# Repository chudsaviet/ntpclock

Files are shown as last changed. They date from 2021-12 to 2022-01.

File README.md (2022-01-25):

NTP synchronized desktop 7-segment clock
=======================================================
Features
--------
1. **NTP** sunchronization using WiFi.
2. **RTC** backup - will show time from a high precision RTC if WiFi is not available.
3. Automatic display **brightness** control.
4. Automatic **timezone** data update from online TZDATA database.
5. Settings via WiFi AP mode and a web page.

Pictures
--------
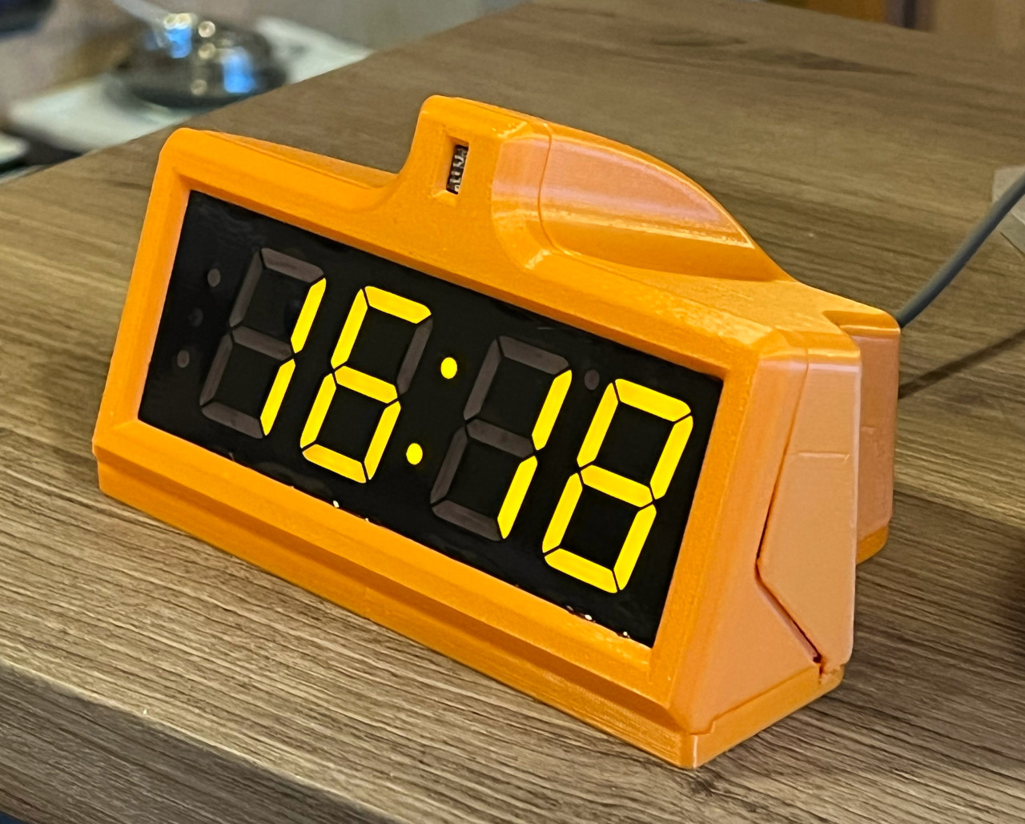
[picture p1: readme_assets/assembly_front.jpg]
Front view

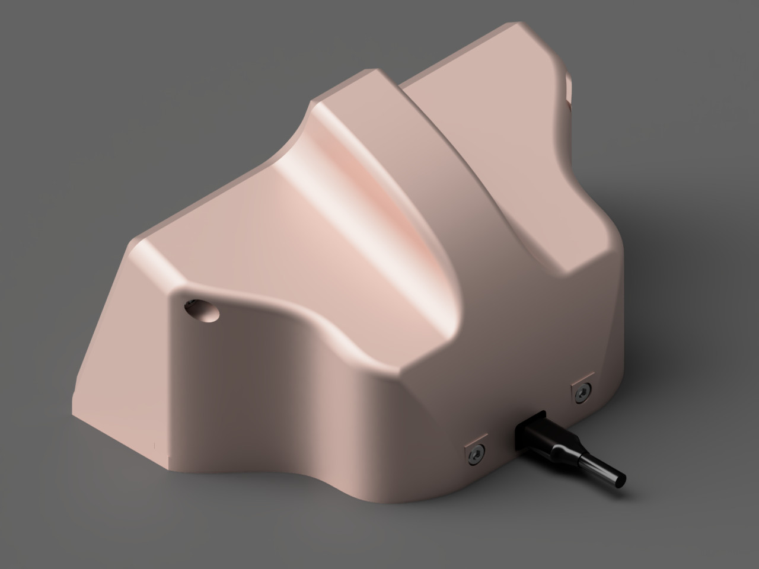
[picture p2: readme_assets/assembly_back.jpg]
Back view

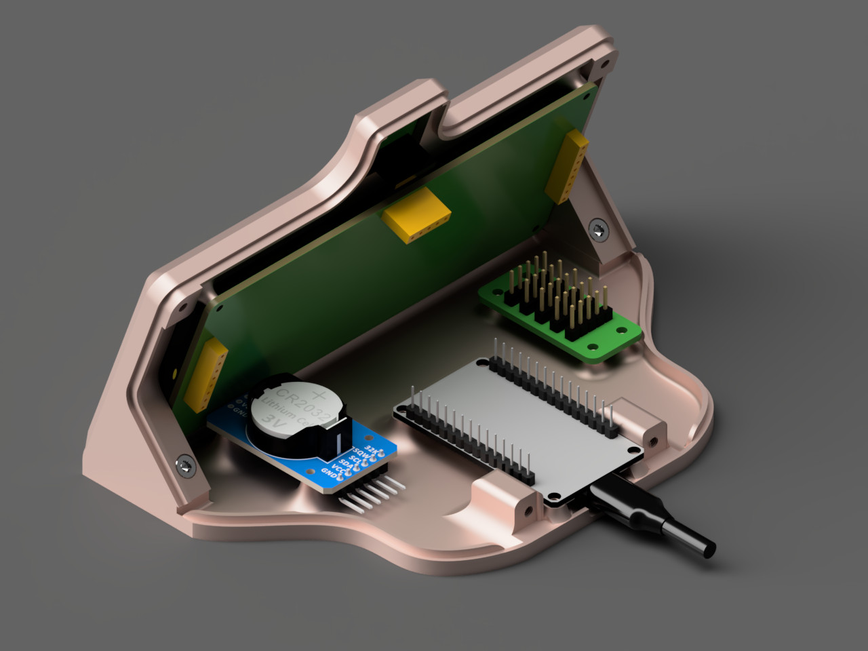
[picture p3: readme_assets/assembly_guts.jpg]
Inside view


Bill of materials
-----------------

| Part | Price |
| --- | ---|
| ESP32, Generic DevKit V1 | $8 |
| Adafruit 1.2" 7-segment display | $18 |
| DS3231*SN* RTC module | $18 |
| Adafruit VEML7700 lux sensor | $5 |
| Custom I2C and power hub board  | $5 |
| Jumper wires, Female-Female | $2 |
| M3, M2.5 and M2 bolts | $5 |
| 3D printed plastic enclosure | $8 |
| Tint film (ex. for cars) | $1 |
| ------------------------------- | ----- |
| Total | $70 |

Building and running the device
-------------------------------
1. Manufacture I2C/Power hub using files from `cad/i2c_header_x5`. Don't forget 3.2K pull-up resistors.
2. 3D print enclosure using files from `cad/enclosure`.
3. Apply tint film to the display module.
4. **Assemble the device.** Select appropriate screw diameter and length for each hole. Connect hub 5V to VIN in ESP32, ground to ground, 3.3V to 3.3V, SDA/SCL to appropriate ESP32 pins. Connect every component to the hub.
5. Install ESP-IDF **v4.4** - https://github.com/espressif/esp-idf/tree/release/v4.4 .
6. Clone repository and **init submodules recursively**.
7. Copy `main/secrets.h` from `main/secrets.h.example` and set your own setting inside.
8. Using instructions from EPS-IDF, build and flash the firmware.

Changing settings after flashing firmware
-----------------------------------------
1. To change settings after flash, connect the device to power and press 'SET' button on the bottom.
2. Device will create a WiFi AP with SSID looking like `ntpclock-XXXXXXXX`.
3. The password will be shown scrolling on display.
4. Connect to AP and open http://192.168.4.1 .

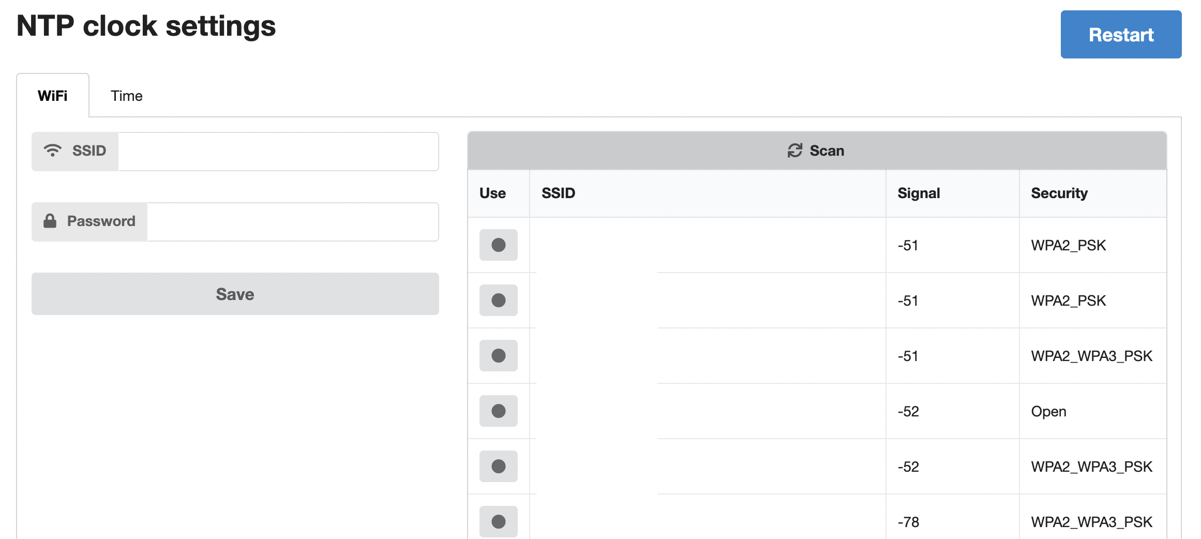
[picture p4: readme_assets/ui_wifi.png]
UI wifi tab

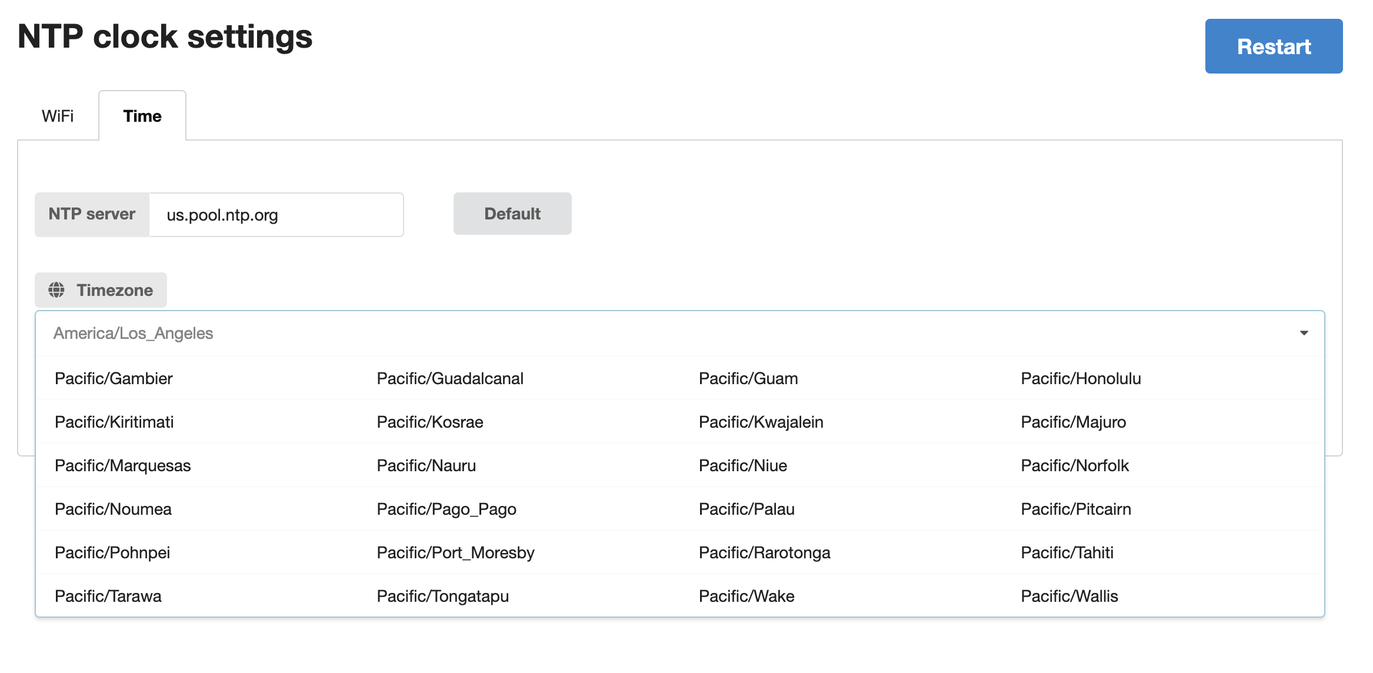
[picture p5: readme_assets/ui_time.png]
UI time tab


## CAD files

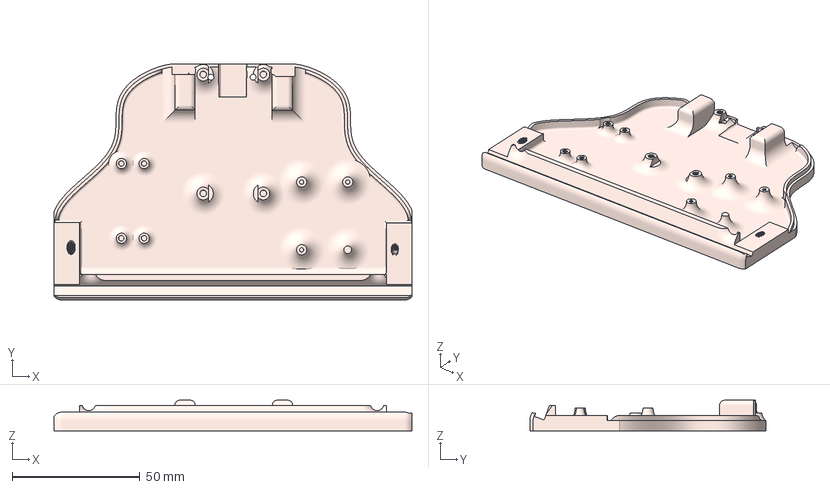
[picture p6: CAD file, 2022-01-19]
cad/enclosure/ntpclock_bottom.3mf
140.0 x 92.4 x 12.0 mm

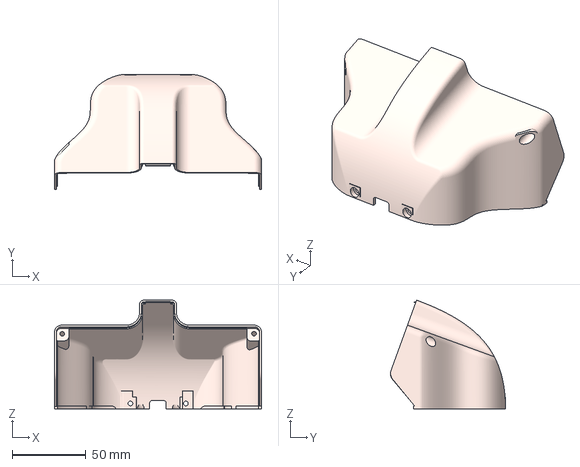
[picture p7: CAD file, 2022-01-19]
cad/enclosure/ntpclock_lid.3mf
140.0 x 77.8 x 73.5 mm

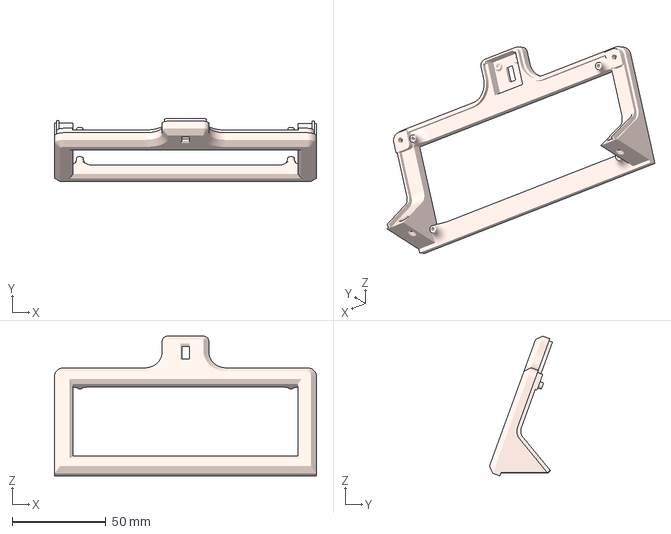
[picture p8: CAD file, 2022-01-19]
cad/enclosure/ntpclock_front.3mf
140.0 x 33.7 x 74.7 mm

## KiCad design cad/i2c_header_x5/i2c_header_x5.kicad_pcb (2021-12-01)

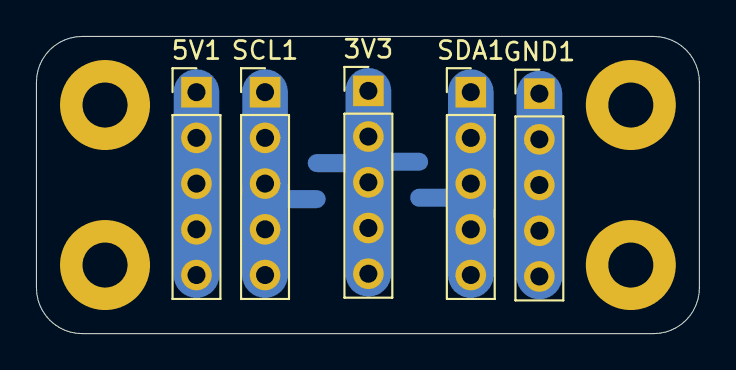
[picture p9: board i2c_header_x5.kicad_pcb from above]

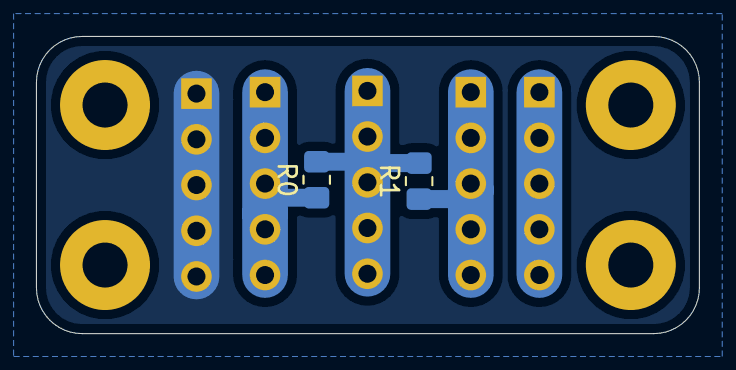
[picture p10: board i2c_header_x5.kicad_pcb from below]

Board: 2 copper layers, 36.8 x 16.5 mm, 7 parts (2 on the bottom side), 5 nets.

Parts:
3V3, 5V1: Conn_01x05_Male; PinHeader_1x05_P2.54mm_Vertical
GND1: Conn_01x05_Male; PinHeader_1x05_P2.54mm_Vertical
R0, R1: 4K7; R_0805_2012Metric_Pad1.20x1.40mm_HandSolder
SCL1: Conn_01x05_Male; PinHeader_1x05_P2.54mm_Vertical
SDA1: Conn_01x05_Male; PinHeader_1x05_P2.54mm_Vertical

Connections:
unnamed: 3V3.1, 3V3.2, 3V3.3, 3V3.4, 3V3.5, R0.2, R1.2
unnamed: 5V1.1, 5V1.2, 5V1.3, 5V1.4, 5V1.5
unnamed: GND1.1, GND1.2, GND1.3, GND1.4, GND1.5
unnamed: R0.1, SDA1.1, SDA1.2, SDA1.3, SDA1.4, SDA1.5
unnamed: R1.1, SCL1.1, SCL1.2, SCL1.3, SCL1.4, SCL1.5

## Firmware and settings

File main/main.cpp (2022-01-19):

#include <stdio.h>
#include <freertos/FreeRTOS.h>
#include <Arduino.h>

#include <esp_sntp.h>

#include <button.h>

#include "wifi_control.h"
#include "filesystem.h"
#include "unique_id.h"
#include "wpa_key_gen.h"
#include "display.h"
#include "als.h"
#include "ntp.h"
#include "rtc.h"
#include "tz_info_local.h"
#include "nvs_local.h"
#include "http/server_control.h"

#include "secrets.h"

#define SET_BUTTON_GPIO 0
#define MAIN_LOOP_DELAY_MS 500

static const char *TAG = "main.cpp";

static QueueHandle_t xButtonEventQueue = 0;

static TaskHandle_t xWifiControlTaskHandle = NULL;

static TaskHandle_t xDisplayTask = NULL;
static QueueHandle_t xDisplayTaskQueue = 0;

static TaskHandle_t xAlsTask = NULL;
static QueueHandle_t xAlsOutputQueue = 0;

static TaskHandle_t xNtpTask = NULL;
static QueueHandle_t xNtpOutputQueue = 0;

static TaskHandle_t xRtcTask = NULL;
static QueueHandle_t xRtcCommandQueue = 0;

static TaskHandle_t xWifiTask = NULL;
static QueueHandle_t xWifiCommandQueue = 0;

static TaskHandle_t xHttpServerControlTask = NULL;
static QueueHandle_t xHttpServerControlQueue = 0;

static TaskHandle_t xTzdataControlTask = NULL;

void setup()
{
    ESP_LOGI(TAG, "Initializing NVS.");
    nvs_begin();

    ESP_LOGI(TAG, "Initializing unique ID.");
    init_unique_id();

    ESP_LOGI(TAG, "Initializing filesystem.");
    filesystem_init();

    ESP_LOGI(TAG, "Creating I2C semaphore.");
    SemaphoreHandle_t i2cSemaphore = xSemaphoreCreateBinary();
    xSemaphoreGive(i2cSemaphore);

    ESP_LOGI(TAG, "Initializing Arduino framework.");
    initArduino();

    ESP_LOGI(TAG, "Starting RTC control task.");
    vStartRtcTask(&xRtcTask, &xRtcCommandQueue, i2cSemaphore);
    RtcMessage rtcMessage = {};
    rtcMessage.command = RtcCommand::DO_SYSTEM_CLOCK_SYNC;
    xQueueSend(xRtcCommandQueue, &rtcMessage, (TickType_t)0);

    ESP_LOGI(TAG, "Starting TZ data control task.");
    vStartTzdataTask(&xTzdataControlTask);

    ESP_LOGI(TAG, "Starting display task.");
    vStartDisplayTask(&xDisplayTask, &xDisplayTaskQueue, i2cSemaphore);

    ESP_LOGI(TAG, "Starting ALS task.");
    vStartAlsTask(&xAlsTask, &xAlsOutputQueue, i2cSemaphore);

    ESP_LOGI(TAG, "Starting WiFi control task.");
    vStartWifiTask(&xWifiTask, &xWifiCommandQueue);

    ESP_LOGI(TAG, "Starting SNTP control task.");
    vStartNtpTask(&xNtpTask, &xNtpOutputQueue, i2cSemaphore);

    ESP_LOGI(TAG, "Starting button watcher task.");
    xButtonEventQueue = button_init(PIN_BIT(SET_BUTTON_GPIO));

    ESP_LOGI(TAG, "Starting WiFi control task.");
    vStartHttpServerControlTask(&xHttpServerControlTask, &xHttpServerControlQueue);
}

void loopIndefinitely()
{
    for (;;)
    {
        button_event_t buttonEvent;
        while (uxQueueMessagesWaiting(xButtonEventQueue) > 0)
        {
            if (xQueueReceive(xButtonEventQueue, &buttonEvent, (TickType_t)0))
            {
                if ((buttonEvent.pin == SET_BUTTON_GPIO) && (buttonEvent.event == BUTTON_UP))
                {
                    char wpa_key[WPA_KEY_LENGTH_CHARS + 1] = {0};
                    generate_wpa_key((char *)&wpa_key);
                    ESP_LOGI(TAG, "Generated WPA key: %s", (char *)&wpa_key);

                    ESP_LOGI(TAG, "Sending WPA key to display.");
                    DisplayCommandMessage displayCommandMessage = {};
                    displayCommandMessage.command = DisplayCommand::SET_SHOW_TEXT;
                    memcpy(displayCommandMessage.payload, &wpa_key, WPA_KEY_LENGTH_CHARS + 1);
                    xQueueSend(xDisplayTaskQueue, &displayCommandMessage, (TickType_t)0);

                    ESP_LOGI(TAG, "Sending WPA key to WiFi control task. Switching to AP mode.");
                    WifiCommandMessage wifiCommandMessage = {};
                    wifiCommandMessage.command = WifiCommand::SWITCH_TO_AP_MODE;
                    memcpy(wifiCommandMessage.payload, &wpa_key, WPA_KEY_LENGTH_CHARS + 1);
                    xQueueSend(xWifiCommandQueue, &wifiCommandMessage, (TickType_t)0);

                    ESP_LOGI(TAG, "Starting webserver.");
                    HttpServerMessage webserverCommandMessage = {};
                    webserverCommandMessage.command = HttpServerCommand::START;
                    xQueueSend(xHttpServerControlQueue, &webserverCommandMessage, (TickType_t)0);
                }
            }
        }

        AlsDataMessage alsDataMessage = {};
        if (xQueueReceive(xAlsOutputQueue, &alsDataMessage, (TickType_t)0))
        {
            ESP_LOGV(TAG, "Got %f lux from ALS. Sending it to display.", alsDataMessage.lux);
            DisplayCommandMessage displayCommandMessage = {};
            displayCommandMessage.command = DisplayCommand::SET_BRIGHTNESS;
            memcpy((void *)displayCommandMessage.payload, (void *)&alsDataMessage.lux, sizeof(float));
            xQueueSend(xDisplayTaskQueue, &displayCommandMessage, (TickType_t)0);
        }

        NtpMessage ntpMessage = {};
        while (uxQueueMessagesWaiting(xNtpOutputQueue) != 0)
        {
            xQueueReceive(xNtpOutputQueue, &ntpMessage, (TickType_t)0);
            switch (ntpMessage.event)
            {
            case NtpEvent::SYNC_HAPPENED:
            {
                ESP_LOGI(TAG, "NtpEvent::SYNC_HAPPENED received.");

                RtcMessage rtcMessage = {};
                rtcMessage.command = RtcCommand::SET_RTC_AUTO_SYSTEM_CLOCK_SYNC;
                rtcMessage.payload[0] = (uint8_t) false;
                xQueueSend(xRtcCommandQueue, &rtcMessage, (TickType_t)0);

                DisplayCommandMessage displayCommandMessage = {};
                displayCommandMessage.command = DisplayCommand::SET_BLINK_COLONS;
                displayCommandMessage.payload[0] = (uint8_t) true;
                xQueueSend(xDisplayTaskQueue, &displayCommandMessage, (TickType_t)0);
            }
            break;
            case NtpEvent::SYNC_TIMEOUT:
            {
                ESP_LOGI(TAG, "NtpEvent::SYNC_TIMEOUT received.");

                RtcMessage rtcMessage = {};
                rtcMessage.command = RtcCommand::SET_RTC_AUTO_SYSTEM_CLOCK_SYNC;
                rtcMessage.payload[0] = (uint8_t) true;
                xQueueSend(xRtcCommandQueue, &rtcMessage, (TickType_t)0);

                DisplayCommandMessage displayCommandMessage = {};
                displayCommandMessage.command = DisplayCommand::SET_BLINK_COLONS;
                displayCommandMessage.payload[0] = (uint8_t) false;
                xQueueSend(xDisplayTaskQueue, &displayCommandMessage, (TickType_t)0);
            }
            break;
            default:
                ESP_LOGE(TAG, "Received unimplemented NTP event: %d .", (uint8_t)ntpMessage.event);
                abort();
                break;
            }
        }

        vTaskDelay(pdMS_TO_TICKS(MAIN_LOOP_DELAY_MS));
    }
}

extern "C" void app_main(void)
{
    setup();
    loopIndefinitely();

    ESP_LOGE(TAG, "Shall never reach end of app_main().");
    abort();
}

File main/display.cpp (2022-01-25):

#include "display.h"

#define TAG "display.cpp"

#include <Arduino.h>
#include <TimeLib.h>

// Can't simply include `time.h` because of conflict with Arduino's `time.h`.
// `esp_sntp.h` seems to include the right one.
#include <esp_sntp.h>

// Otherwise `Adafruit LEDBackpack` -> `Adafruit GFX` fails to build.
#include <Adafruit_I2CDevice.h>
#include <Adafruit_LEDBackpack.h>

#include "tz_info_local.h"

#define DISPLAY_TASK_CORE 1
#define DISPLAY_COMMAND_QUEUE_SIZE 8

#define DISPLAY_I2C_ADDRESS 0x70
#define DISPLAY_BEGIN_SEMAPHORE_TIMEOUT_MS 2048
#define DISPLAY_UPDATE_SEMAPHORE_TIMEOUT_MS 512

#define DISPLAY_LOOP_DELAY_MS 128L
#define DISPLAY_MAX_BRIGHTNESS 16L
#define DISPLAY_MIN_BRIGNTNESS 0L
#define DISPLAY_MAX_LUX 500.0F
#define DISPLAY_CHARS 4

enum DisplayShowMode
{
    TIME,
    TEXT
};

static Adafruit_7segment clockDisplay = Adafruit_7segment();
static bool blinkColons = false;
static SemaphoreHandle_t i2cSemaphore = 0;
static QueueHandle_t xCommandQueue = 0;
static float currentBrightness = 0.0;
static DisplayShowMode currentMode = DisplayShowMode::TIME;
static char *currentText = NULL;
static size_t currentTextLength = 0;
static int64_t textShowStartTimestamp = 0;

void displayBegin()
{
    if (xSemaphoreTake(i2cSemaphore, pdMS_TO_TICKS(DISPLAY_BEGIN_SEMAPHORE_TIMEOUT_MS)) == pdPASS)
    {
        clockDisplay.begin(DISPLAY_I2C_ADDRESS);
        xSemaphoreGive(i2cSemaphore);
    }
    else
    {
        Serial.println("displayBegin: couldn't take i2c semaphore.");
    }
}

void vDisplayTime()
{
    timeval currentTime;
    gettimeofday(&currentTime, NULL);
    currentTime.tv_sec = utc2local(currentTime.tv_sec);

    if (xSemaphoreTake(i2cSemaphore, pdMS_TO_TICKS(DISPLAY_UPDATE_SEMAPHORE_TIMEOUT_MS)) == pdPASS)
    {
        clockDisplay.clear();
        clockDisplay.setBrightness(currentBrightness);

        int currentHour = hour(currentTime.tv_sec);
        int currentMinute = minute(currentTime.tv_sec);

        uint8_t hourFirstDigit = currentHour / 10;
        uint8_t hourSecondDigit = currentHour % 10;
        uint8_t minuteFirstDigit = currentMinute / 10;
        uint8_t minuteSecondDigit = currentMinute % 10;

        if (hourFirstDigit > 0)
        {
            clockDisplay.writeDigitNum(0, hourFirstDigit);
        }
        clockDisplay.writeDigitNum(1, hourSecondDigit);
        clockDisplay.writeDigitNum(3, minuteFirstDigit);
        clockDisplay.writeDigitNum(4, minuteSecondDigit);
        
        if (blinkColons)
        {
            clockDisplay.drawColon(second(currentTime.tv_sec) % 2 == 0);
        }
        else
        {
            clockDisplay.drawColon(true);
        }
        clockDisplay.writeDisplay();

        xSemaphoreGive(i2cSemaphore);
    }
    else
    {
        Serial.println("displayUpdate: couldn't take i2c semaphore.");
    }
}

void vDisplayText()
{
    char finalText[DISPLAY_CHARS] = {0};

    if (currentTextLength <= DISPLAY_CHARS)
    {

        strncpy((char *)&finalText, currentText, currentTextLength);
    }
    else
    {
        uint8_t textShift = ((esp_timer_get_time() - textShowStartTimestamp) / 1000000) % currentTextLength;
        size_t tailLen = currentTextLength - textShift;
        ESP_LOGV(TAG, "vDisplayText() textShift: %d tailLen: %d", textShift, tailLen);
        if (tailLen < DISPLAY_CHARS)
        {
            memcpy(&finalText, currentText + textShift, tailLen);
            memcpy((char *)&finalText + tailLen, currentText, DISPLAY_CHARS - tailLen);
        }
        else
        {
            memcpy(&finalText, currentText + textShift, DISPLAY_CHARS);
        }
    }

    if (xSemaphoreTake(i2cSemaphore, pdMS_TO_TICKS(DISPLAY_UPDATE_SEMAPHORE_TIMEOUT_MS)) == pdPASS)
    {
        clockDisplay.println();
        clockDisplay.drawColon(false);
        clockDisplay.setBrightness(currentBrightness);
        for (uint8_t i = 0; i < DISPLAY_CHARS; i++)
        {
            clockDisplay.write(finalText[i]);
        }

        clockDisplay.writeDisplay();
        xSemaphoreGive(i2cSemaphore);
    }
    else
    {
        Serial.println("vDisplayText(): couldn't take i2c semaphore.");
    }
}

void setBrightness(float lux)
{
    float k = lux / DISPLAY_MAX_LUX;
    currentBrightness = min(DISPLAY_MAX_BRIGHTNESS,
                            DISPLAY_MIN_BRIGNTNESS +
                                static_cast<uint8_t>(
                                    static_cast<float>(DISPLAY_MAX_BRIGHTNESS - DISPLAY_MIN_BRIGNTNESS) * k));
}

void vDisplayTask(void *pvParameters)
{
    SemaphoreHandle_t i2cSemaphore = *((SemaphoreHandle_t *)pvParameters);
    displayBegin();

    for (;;)
    {
        while (uxQueueMessagesWaiting(xCommandQueue) != 0)
        {
            DisplayCommandMessage message = {};
            xQueueReceive(xCommandQueue, &message, (TickType_t)0);
            switch (message.command)
            {
            case DisplayCommand::SET_BRIGHTNESS:
            {
                float lux = 0;
                memcpy(&lux, &message.payload, sizeof(float));
                setBrightness(lux);
            }
            break;
            case DisplayCommand::SET_BLINK_COLONS:
            {
                blinkColons = (message.payload[0] > 0);
            }
            break;
            case DisplayCommand::SET_SHOW_TIME:
            {
                currentMode = DisplayShowMode::TIME;
            }
            break;
            case DisplayCommand::SET_SHOW_TEXT:
            {
                currentMode = DisplayShowMode::TEXT;
                currentTextLength = strlen((char *)&message.payload);
                currentText = (char *)malloc(currentTextLength + 2);
                strncpy(currentText, (char *)&message.payload, currentTextLength + 1);
                currentText[currentTextLength] = ' ';
                currentText[currentTextLength + 1] = 0;
                currentTextLength += 1;
                textShowStartTimestamp = esp_timer_get_time();
                ESP_LOGI(TAG, "Will show: '%s'", currentText);
            }
            break;
            default:
                ESP_LOGE(TAG, "Unknown DisplayCommand received: %d", (uint8_t)message.command);
                abort();
                break;
            }
        }

        switch (currentMode)
        {
        case DisplayShowMode::TIME:
            vDisplayTime();
            break;
        case DisplayShowMode::TEXT:
            vDisplayText();
            break;
        default:
            ESP_LOGE(TAG, "Unknown DisplayShowMode received: %d", (uint8_t)currentMode);
            abort();
            break;
        }

        vTaskDelay(pdMS_TO_TICKS(DISPLAY_LOOP_DELAY_MS));
    }
    vTaskDelete(NULL);
}
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

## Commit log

2021-08-28 Added Time and TimeZoneInfo libraries. Prototyped timezone conversion.
2021-08-29 Ticking using hardware timer.
2021-08-30 Implemented more reasonable RTC/NTP switchover.
2021-09-04 Added WiFi reconnection on NTP sync failure.
    [ntp.cpp, wifi.cpp]
2021-09-06 Added lux sensor code.
2021-09-28 Mitigated millis() overflow.
2021-10-13 Moved display update from interrupt to main loop to avoid I2C race conditions.
    [main.cpp]
2021-10-14 Updated WiFiNINA. Added wait for WiFi up when waking up from low power mode. Resolving NTP server name every time.
2021-10-19 Switched to esp32.
2021-10-24 Removec WiFi low power functions. WiFi power saving is done automatically in ESP32.
2021-10-31 Switched to esp-idf time keeping and SNTP client.
2021-11-01 Fixed timezone conversion issues.
    [display.cpp, main.cpp, rtc.cpp]
2021-11-04 Added i2c semaphore. Increased NTP sync timeout to 4h.
2021-11-18 Added CAD files (export from Fusion360).
    [ntpclock_bottom.3mf, ntpclock_front.3mf, ntpclock_lid.3mf]
2021-11-19 Moved enclosure CAD files to cad/enclosure.
    [ntpclock_bottom.3mf, ntpclock_front.3mf, ntpclock_lid.3mf]
2021-11-19 Added i2c_header_x5 KiCad PCB project.
    [i2c_header_x5-B_Cu.gbr, i2c_header_x5-B_Mask.gbr, i2c_header_x5-B_Paste.gbr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]
2021-11-29 Migrated to ESP-IDF and Arduino as ESP-IDF component.
2021-12-01 Switched to ESP-IDF native app_main() and native WiFi API.
2021-12-01 Added SMD pull-up resistors to i2c header.
    [i2c_header_x5-B_Cu.gbr, i2c_header_x5-B_Mask.gbr, i2c_header_x5-B_Paste.gbr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]
2021-12-06 Moved WiFi control to a separate task. Implemented reconnection in case of failure.
    [main.cpp, rtc.cpp]
2021-12-12 Added SPIFFS partition.
    [partitions.csv]
2021-12-13 Enclosure refinements. v127
    [ntpclock_bottom.3mf, ntpclock_front.3mf, ntpclock_lid.3mf]
2021-12-14 Added button tracking using esp32-button component.
2021-12-14 Fixed button labels.
    [ntpclock_bottom.3mf]
2021-12-27 Starting AP mode when SET button pressed.
2021-12-27 Started webserver implementation.
    [partitions.csv]
2022-01-06 Created initial web UI with Semantic (Formantic) UI.
    [partitions.csv]
2022-01-11 Added working Set button to SSID list.
2022-01-19 Added timezone setting and automated update (#3)
    Added timezone setting and automated update
    [ntpclock_bottom.3mf, ntpclock_front.3mf, ntpclock_lid.3mf]
2022-01-19 Fix for displaying time after midnight (#4)
    [display.cpp]
